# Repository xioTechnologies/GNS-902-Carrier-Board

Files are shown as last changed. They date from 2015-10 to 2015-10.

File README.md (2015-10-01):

GNS-902-Carrier-Board
=====================

Carrier board for the [GNS 902 GPS](http://www.gns-gmbh.com/index.php?id=271) module.  Includes CR2032 back up battery and LED to indicate fix status.  The header pinout is compatible with a 3.3V [FTDI device](https://www.sparkfun.com/products/9873).

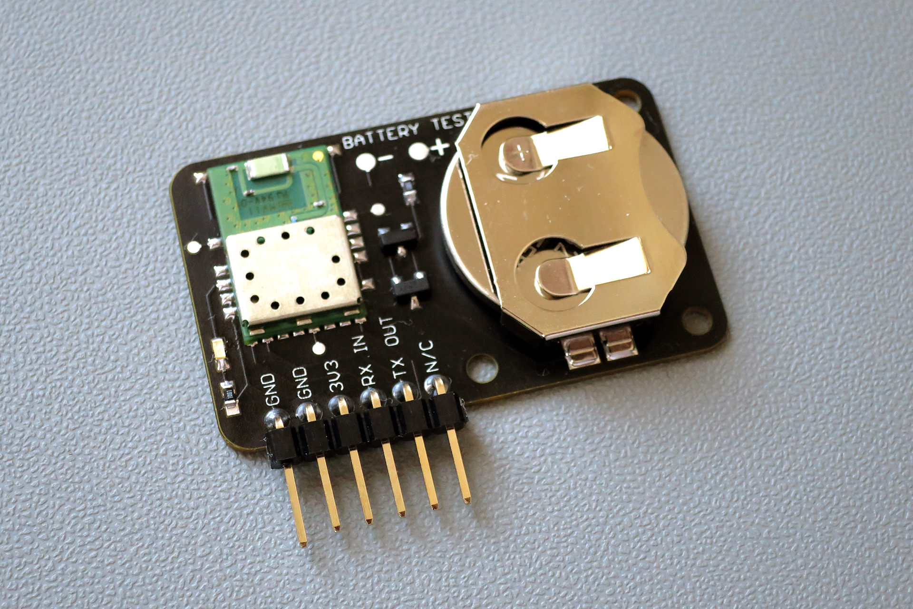
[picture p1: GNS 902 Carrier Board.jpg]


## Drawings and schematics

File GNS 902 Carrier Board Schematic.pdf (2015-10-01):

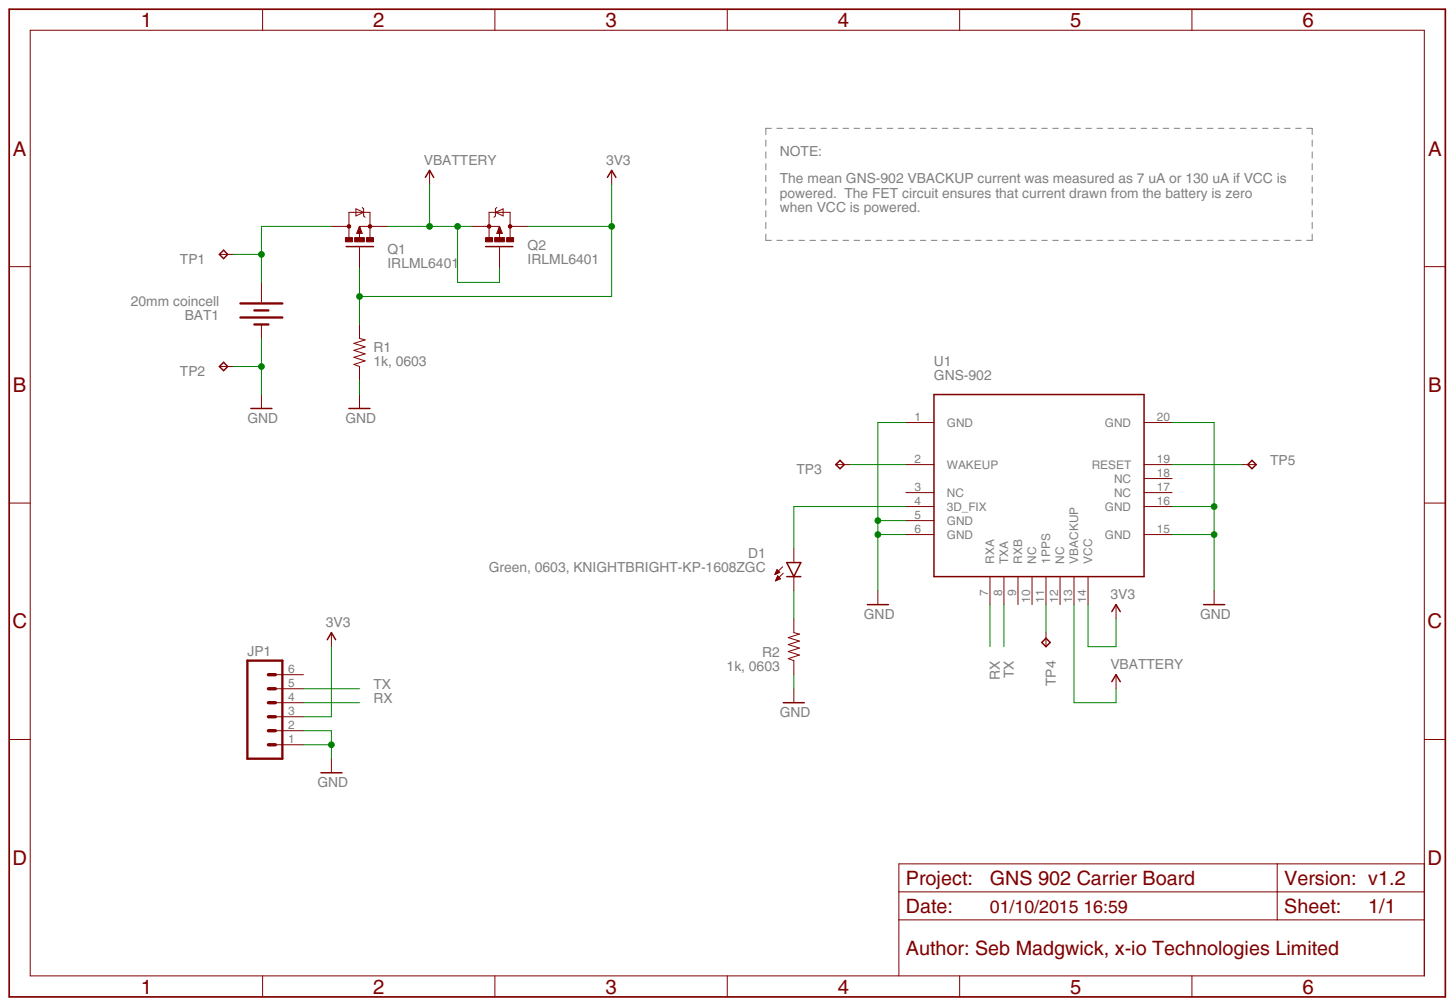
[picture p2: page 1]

The mean GNS-902 VBACKUP current was measured as 7 uA or 130 uA if VCC is powered. The FET circuit ensures that current drawn from the battery is zero when VCC is powered. NOTE:

Project: GNS 902 Carrier Board | Version: v1.2
Date: 01/10/2015 16:59 | Sheet: 1/1

Author: Seb Madgwick, x-io Technologies Limited

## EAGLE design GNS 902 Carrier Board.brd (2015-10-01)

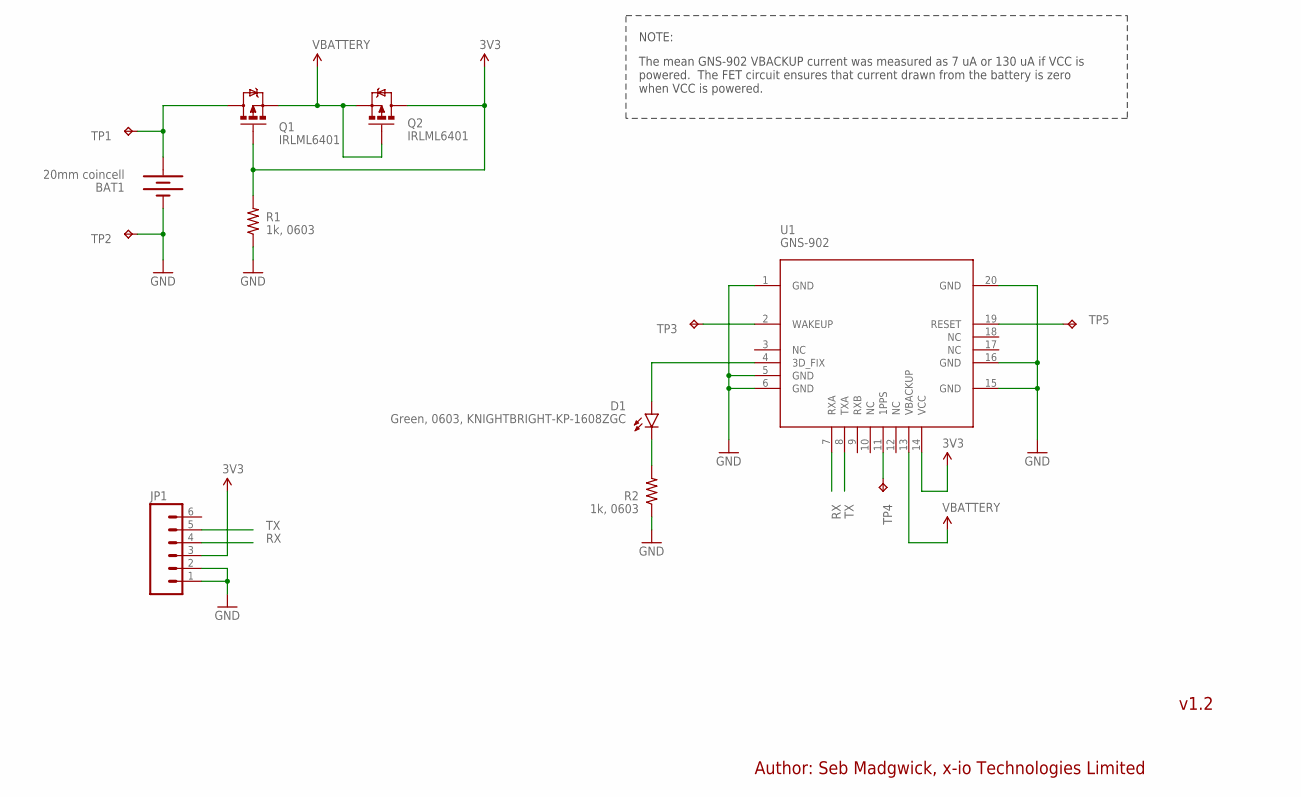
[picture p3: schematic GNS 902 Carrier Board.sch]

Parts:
BAT1: 20mm coincell; BATTCON_20MM_4LEGS
D1: Green, 0603, KNIGHTBRIGHT-KP-1608ZGC; LED-0603
JP1: M06NO_SILK_FEMALE_PTH; 1X06_NO_SILK
Q1, Q2: IRLML6401; SOT23-3
R1, R2: 1k, 0603; 0603-RES
TP1, TP2: TPTP15R; TP15R
TP3, TP4, TP5: TPTP10R; TP10R
U1: GNS-902

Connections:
3V3: JP1.3, Q1.1 (G), Q2.3 (D), R1.2, U1.14 (VCC)
GND: BAT1.2 (-), JP1.1, JP1.2, R1.1, R2.1, TP2.TP, U1.1 (GND), U1.5 (GND), U1.6 (GND), U1.15 (GND), U1.16 (GND), U1.20 (GND)
unnamed: D1.A, U1.4 (3D_FIX)
unnamed: D1.C, R2.2
unnamed: TP3.TP, U1.2 (WAKEUP)
unnamed: TP4.TP, U1.11 (1PPS)
unnamed: TP5.TP, U1.19 (RESET)
unnamed: BAT1.1 (+), Q1.3 (D), TP1.TP
RX: JP1.4, U1.7 (RXA)
TX: JP1.5, U1.8 (TXA)
VBATTERY: Q1.2 (S), Q2.1 (G), Q2.2 (S), U1.13 (VBACKUP)

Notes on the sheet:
v1.2
Author: Seb Madgwick, x-io Technologies Limited
The mean GNS-902 VBACKUP current was measured as 7 uA or 130 uA if VCC is powered. The FET circuit ensures that current drawn from the battery is zero when VCC is powered.
NOTE:

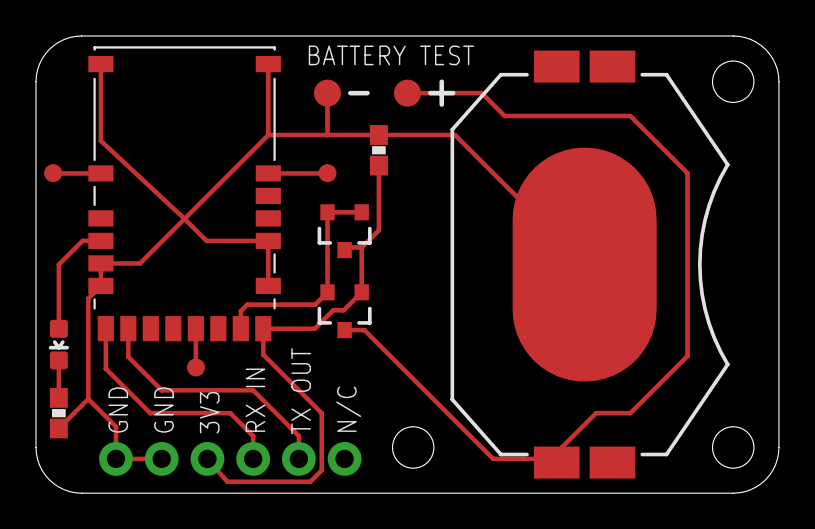
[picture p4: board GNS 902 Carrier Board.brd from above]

Board: 2 copper layers, 41.3 x 25.4 mm, 13 parts (0 on the bottom side), 11 nets.

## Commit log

2015-09-14 Commit project files
    [GNS 902 Carrier Board.brd, GNS 902 Carrier Board.sch]
2015-09-20 Add automatic VBACKUP power source switch
    [GNS 902 Carrier Board.brd, GNS 902 Carrier Board.sch]
2015-10-01 Add photo of assembled PCB
2015-10-01 Correct GNS-902 footprint and add notes to schematic
    [GNS 902 Carrier Board.brd, GNS 902 Carrier Board.sch]

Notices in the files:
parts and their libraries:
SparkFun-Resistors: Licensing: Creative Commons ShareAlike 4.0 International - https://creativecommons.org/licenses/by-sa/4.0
